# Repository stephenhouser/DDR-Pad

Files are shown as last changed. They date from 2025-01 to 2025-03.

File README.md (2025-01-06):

---
category: woodworking
---

## Todo

- √ Clear acrylic ~ 12x12x 0.354 @ 10 = 180 + $50 shipping
 - https://www.tapplastics.com/product/plastics/cut_to_size_plastic/polycarbonate_sheets/516
 - 2024/01/01 - orderd 10 11x11x0.354" (3/8")
 - $229.94
- √ M6 Screws, M6 Nylon nuts -- Granger
 - 2024/01/03 Picked up nuts, screws on backorder to 2024/01/08
 - $60
	
- Decals ~ $70
 - https://www.bannerbuzz.com/clear-window-decals/p

- Arduino/teensy -- will it be fast enough?
 - perhaps microcontrollers at each pad sending data and lights?

- Metal corners?
 - 16 gague, need sheet brake (Rex?)

- 1.25" SteelTex no-thread pipe -- will it be sturdy enough
 - 1.25 is only in silver color
 - 2 bases, 2 90-deg, 3 poles

## The Build we are working from

- The hardware: [DIY Arcade DDR Metal Dance Pad With LED Under $500](https://www.instructables.com/DIY-Arcade-DDR-Metal-Dance-Pad-With-LED-Under-500/)
- The electronics: [6 Panel DDR USB Controller With LED](https://www.instructables.com/6-Panel-DDR-USB-Controller-With-LED/)

## Other Builds

- [Mystic Steps build](https://www.mysticsteps.com/diy-pad/), uses a AtMega32U (32u chipset for USB I imagine)
- [andrewhlu's build](https://andrewhlu.com/ddr/), uses [STM32L476G board](https://www.digikey.com/en/products/detail/stmicroelectronics/STM32L476G-DISCO/5344355)
- [Sensor Channels](https://www.thingiverse.com/thing:4547247) on Thingiverse, replacements for original DDR

## Making Pads

- https://www.hackmycab.com/?portfolio=arrow-panels-part-1-making-new-polycarb-panels
- https://www.hackmycab.com/?portfolio=arrow-panels-part-2-arrow-decals

## Lights

- [8x6 Lights](https://ddrpad.com/collections/arcade-parts/products/arcade-pad-led-light-mod) for original DDR
- [8x8 addressable LED modules](https://www.amazon.com/WS2812B-Flexible-Individually-Addressable-64Pixels/dp/B09KBZT6LD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) from Amazon
 - ws2812 should be able to do about 64fps with 512 in a chain.
 - will need power injection at each row?
 - https://electronics.stackexchange.com/questions/338248/ws2812b-response-time

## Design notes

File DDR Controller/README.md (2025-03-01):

# DDR Master Controller

Simple keyboard controller for DDR Pad using Teensy 3.2 and teensy's keyboard module (https://www.pjrc.com/teensy/td_keyboard.html)

## TODO

- Use exposed GPIO with jumper or switch to configure for 4-pad (NESW), 8-pad (N, NE, E, SE, S, SW, W, NW), or all 9 pads active.

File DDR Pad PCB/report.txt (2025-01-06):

Info: Front (top side) placement file: '/Users/houser/Projects/DDR Pad (Shawn)/DDR Well v1.0/gerber-v1.0/DDR Pad-top-pos.csv'.
Info: Component count: 16.
Info: Back (bottom side) placement file: '/Users/houser/Projects/DDR Pad (Shawn)/DDR Well v1.0/gerber-v1.0/DDR Pad-bottom-pos.csv'.
Info: Component count: 0.
Info: Full component count: 16.
Info: File generation successful.

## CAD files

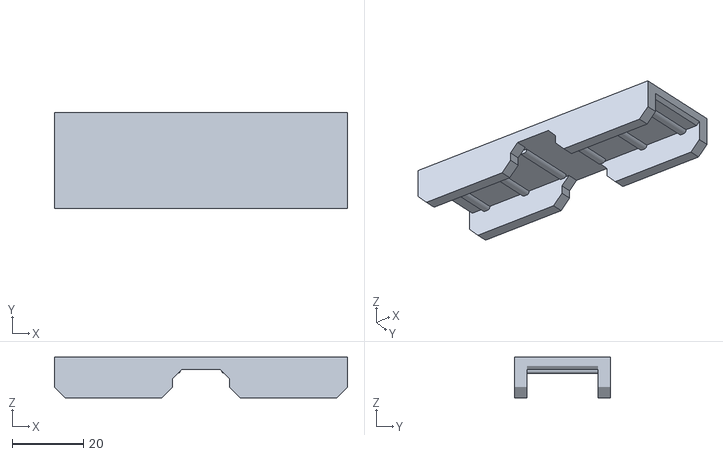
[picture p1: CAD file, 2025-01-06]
Sensor Holders/Sensor+holder+Top.stl
82.0 x 27.0 x 11.4

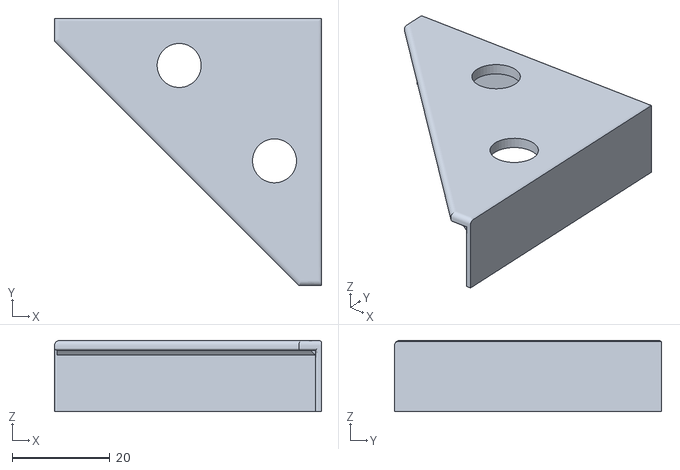
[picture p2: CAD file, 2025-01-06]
Sensor Holders/Active+Corner+Bracket.stl
54.6 x 54.6 x 14.5

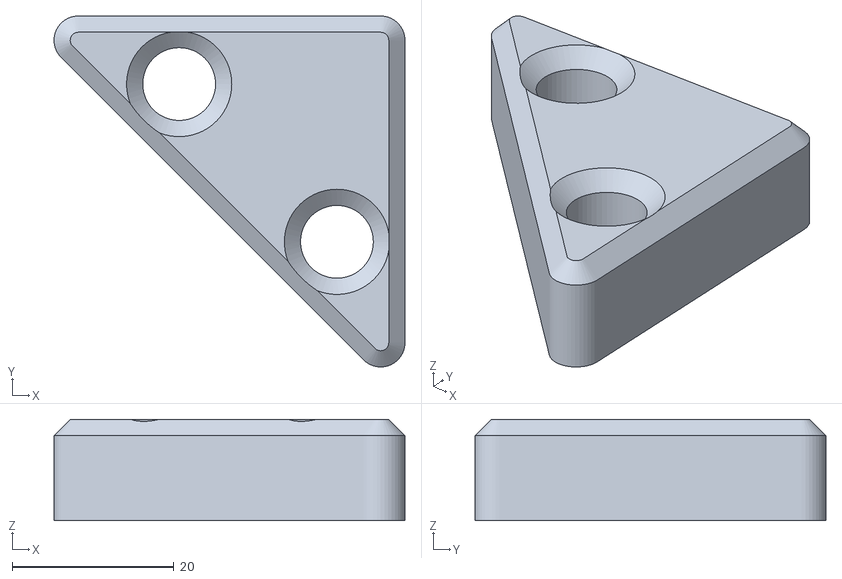
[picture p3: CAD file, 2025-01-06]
Sensor Holders/DDRCornerBracketTrianglev2.stl
43.4 x 43.4 x 12.5

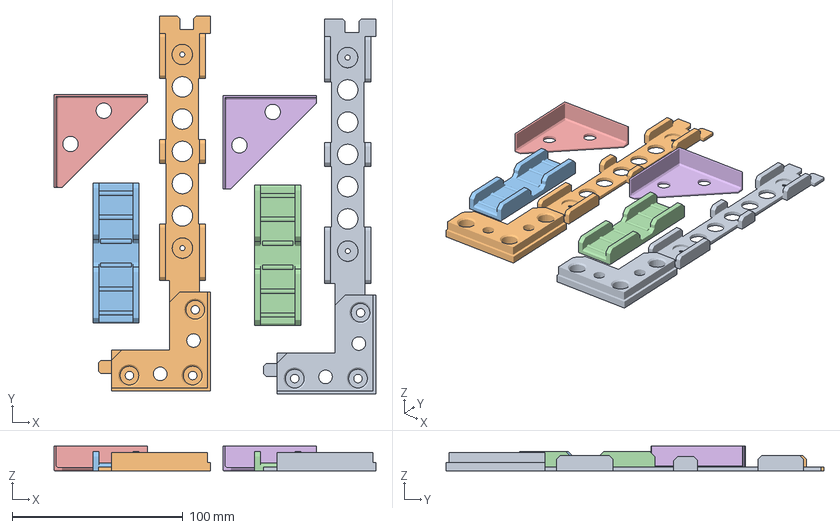
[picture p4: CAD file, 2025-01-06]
Sensor Holders/DDRPActive_Bracket_BaseV2.3mf
188.3 x 221.2 x 14.5 mm
DDRPActive_Bracket_BaseV2.stl x 2
Sensor+holder+Top.stl x 2
Active+Corner+Bracket.stl x 2

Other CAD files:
Sensor Holders/DDRPActive_Bracket_BaseV2.stl

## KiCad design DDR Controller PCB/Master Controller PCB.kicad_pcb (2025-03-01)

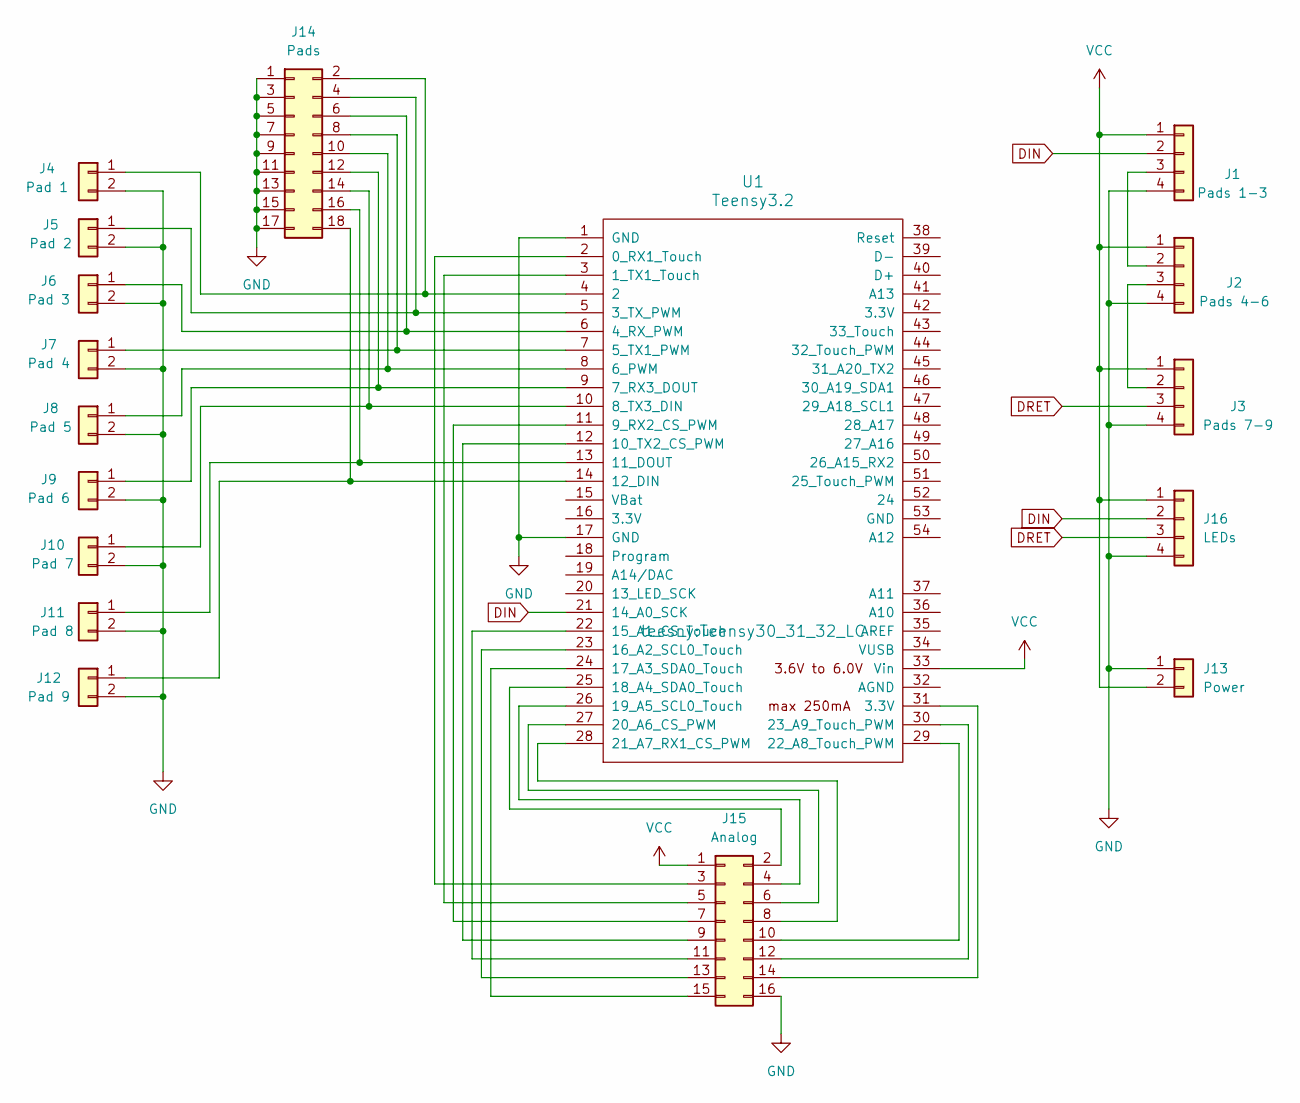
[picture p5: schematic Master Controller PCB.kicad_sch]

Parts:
J1: Pads 1-3; JST_XH_B4B-XH-A_1x04_P2.50mm_Vertical
J2: Pads 4-6; JST_XH_B4B-XH-A_1x04_P2.50mm_Vertical
J3: Pads 7-9; JST_XH_B4B-XH-A_1x04_P2.50mm_Vertical
J4: Pad 1; JST_XH_B2B-XH-A_1x02_P2.50mm_Vertical
J5: Pad 2; JST_XH_B2B-XH-A_1x02_P2.50mm_Vertical
J6: Pad 3; JST_XH_B2B-XH-A_1x02_P2.50mm_Vertical
J7: Pad 4; JST_XH_B2B-XH-A_1x02_P2.50mm_Vertical
J8: Pad 5; JST_XH_B2B-XH-A_1x02_P2.50mm_Vertical
J9: Pad 6; JST_XH_B2B-XH-A_1x02_P2.50mm_Vertical
J10: Pad 7; JST_XH_B2B-XH-A_1x02_P2.50mm_Vertical
J11: Pad 8; JST_XH_B2B-XH-A_1x02_P2.50mm_Vertical
J12: Pad 9; JST_XH_B2B-XH-A_1x02_P2.50mm_Vertical
J13: Power; screw_terminal_01x02_p7.62mm
J14: Pads; PinHeader_2x09_P2.54mm_Vertical
J15: Analog; PinHeader_2x08_P2.54mm_Vertical
J16: LEDs; PinHeader_1x04_P2.54mm_Vertical
U1: Teensy3.2; Teensy30_31_32_LC

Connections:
DIN: J1.2, J16.2, U1.21 (14_A0_SCK)
DRET: J3.3, J16.3
GND: J1.4, J2.4, J3.4, J4.2, J5.2, J6.2, J7.2, J8.2, J9.2, J10.2, J11.2, J12.2, J13.1, J14.1, J14.3, J14.5, J14.7, J14.9, J14.11, J14.13, J14.15, J14.17, J15.16, J16.4, U1.1 (GND), U1.17 (GND)
unnamed: J1.3, J2.2
unnamed: J2.3, J3.2
unnamed: J10.1, J14.14, U1.10 (8_TX3_DIN)
unnamed: J11.1, J14.16, U1.13 (11_DOUT)
unnamed: J12.1, J14.18, U1.14 (12_DIN)
unnamed: J4.1, J14.2, U1.4 (2)
unnamed: J5.1, J14.4, U1.5 (3_TX_PWM)
unnamed: J6.1, J14.6, U1.6 (4_RX_PWM)
unnamed: J7.1, J14.8, U1.7 (5_TX1_PWM)
unnamed: J8.1, J14.10, U1.8 (6_PWM)
unnamed: J9.1, J14.12, U1.9 (7_RX3_DOUT)
unnamed: J15.2, U1.25 (18_A4_SDA0_Touch)
unnamed: J15.3, U1.2 (0_RX1_Touch)
unnamed: J15.4, U1.26 (19_A5_SCL0_Touch)
unnamed: J15.5, U1.3 (1_TX1_Touch)
unnamed: J15.6, U1.27 (20_A6_CS_PWM)
unnamed: J15.7, U1.11 (9_RX2_CS_PWM)
unnamed: J15.8, U1.28 (21_A7_RX1_CS_PWM)
unnamed: J15.9, U1.12 (10_TX2_CS_PWM)
unnamed: J15.10, U1.29 (22_A8_Touch_PWM)
unnamed: J15.11, U1.22 (15_A1_CS_Touch)
unnamed: J15.12, U1.30 (23_A9_Touch_PWM)
unnamed: J15.13, U1.23 (16_A2_SCL0_Touch)
unnamed: J15.14, U1.31 (3.3V)
unnamed: J15.15, U1.24 (17_A3_SDA0_Touch)
VCC: J1.1, J2.1, J3.1, J13.2, J15.1, J16.1, U1.33 (Vin)

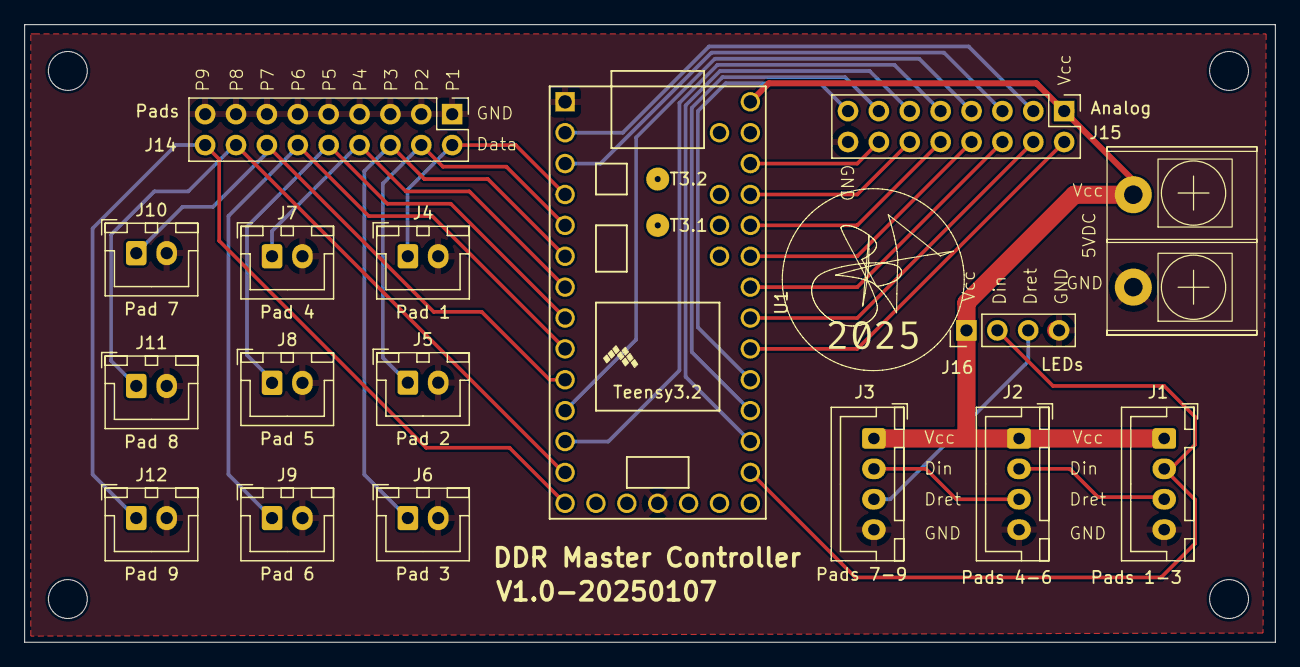
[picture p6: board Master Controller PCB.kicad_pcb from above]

Board: 2 copper layers, 102.9 x 50.8 mm, 17 parts (0 on the bottom side), 29 nets.

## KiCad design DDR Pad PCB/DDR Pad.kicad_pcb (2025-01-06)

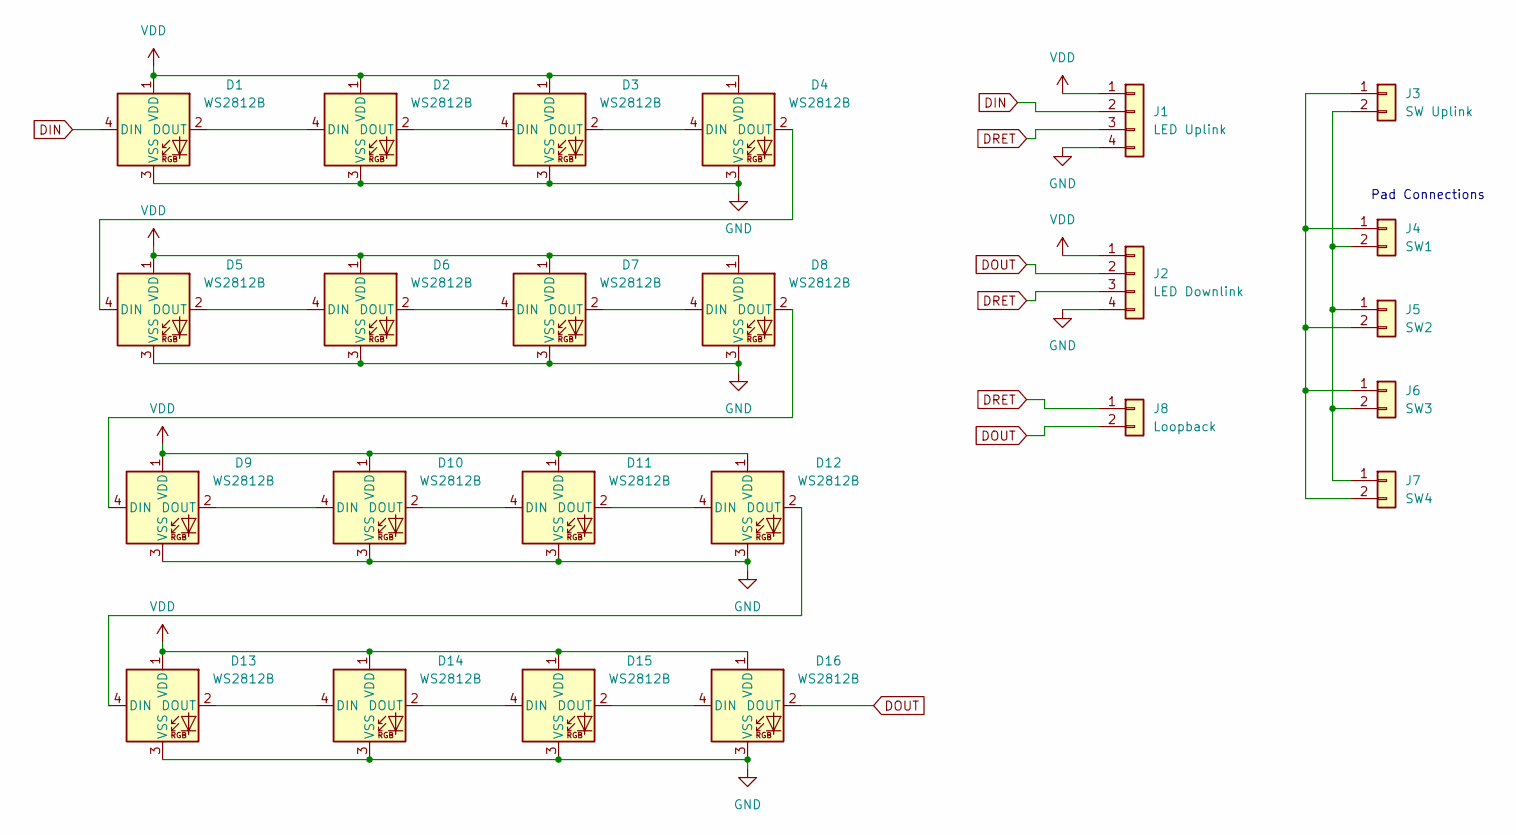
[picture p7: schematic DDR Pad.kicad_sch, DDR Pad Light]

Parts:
D1, D2, D3, D4, D5, D6, D7, D8, D9, D10, D11, D12, D13, D14, D15, D16: WS2812B; LED_WS2812B_PLCC4_5.0x5.0mm_P3.2mm; LCSC C2846931
J1: LED Uplink; JST_XH_S4B-XH-A_1x04_P2.50mm_Horizontal
J2: LED Downlink; JST_XH_S4B-XH-A_1x04_P2.50mm_Horizontal
J3: SW Uplink; JST_XH_S2B-XH-A-1_1x02_P2.50mm_Horizontal
J4: SW1; JST_XH_S2B-XH-A-1_1x02_P2.50mm_Horizontal
J5: SW2; JST_XH_S2B-XH-A-1_1x02_P2.50mm_Horizontal
J6: SW3; JST_XH_S2B-XH-A-1_1x02_P2.50mm_Horizontal
J7: SW4; JST_XH_S2B-XH-A-1_1x02_P2.50mm_Horizontal
J8: Loopback; PinHeader_1x02_P2.54mm_Vertical

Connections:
DIN: D1.4 (DIN), J1.2
DOUT: D16.2 (DOUT), J2.2, J8.2
DRET: J1.3, J2.3, J8.1
GND: D1.3 (VSS), D2.3 (VSS), D3.3 (VSS), D4.3 (VSS), D5.3 (VSS), D6.3 (VSS), D7.3 (VSS), D8.3 (VSS), D9.3 (VSS), D10.3 (VSS), D11.3 (VSS), D12.3 (VSS), D13.3 (VSS), D14.3 (VSS), D15.3 (VSS), D16.3 (VSS), J1.4, J2.4
unnamed: D1.2 (DOUT), D2.4 (DIN)
unnamed: D2.2 (DOUT), D3.4 (DIN)
unnamed: D3.2 (DOUT), D4.4 (DIN)
unnamed: D4.2 (DOUT), D5.4 (DIN)
unnamed: D5.2 (DOUT), D6.4 (DIN)
unnamed: D6.2 (DOUT), D7.4 (DIN)
unnamed: D7.2 (DOUT), D8.4 (DIN)
unnamed: D8.2 (DOUT), D9.4 (DIN)
unnamed: D9.2 (DOUT), D10.4 (DIN)
unnamed: D10.2 (DOUT), D11.4 (DIN)
unnamed: D11.2 (DOUT), D12.4 (DIN)
unnamed: D12.2 (DOUT), D13.4 (DIN)
unnamed: D13.2 (DOUT), D14.4 (DIN)
unnamed: D14.2 (DOUT), D15.4 (DIN)
unnamed: D15.2 (DOUT), D16.4 (DIN)
unnamed: J3.1, J4.1, J5.2, J6.1, J7.2
unnamed: J3.2, J4.2, J5.1, J6.2, J7.1
VDD: D1.1 (VDD), D2.1 (VDD), D3.1 (VDD), D4.1 (VDD), D5.1 (VDD), D6.1 (VDD), D7.1 (VDD), D8.1 (VDD), D9.1 (VDD), D10.1 (VDD), D11.1 (VDD), D12.1 (VDD), D13.1 (VDD), D14.1 (VDD), D15.1 (VDD), D16.1 (VDD), J1.1, J2.1

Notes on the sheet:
Pad Connections

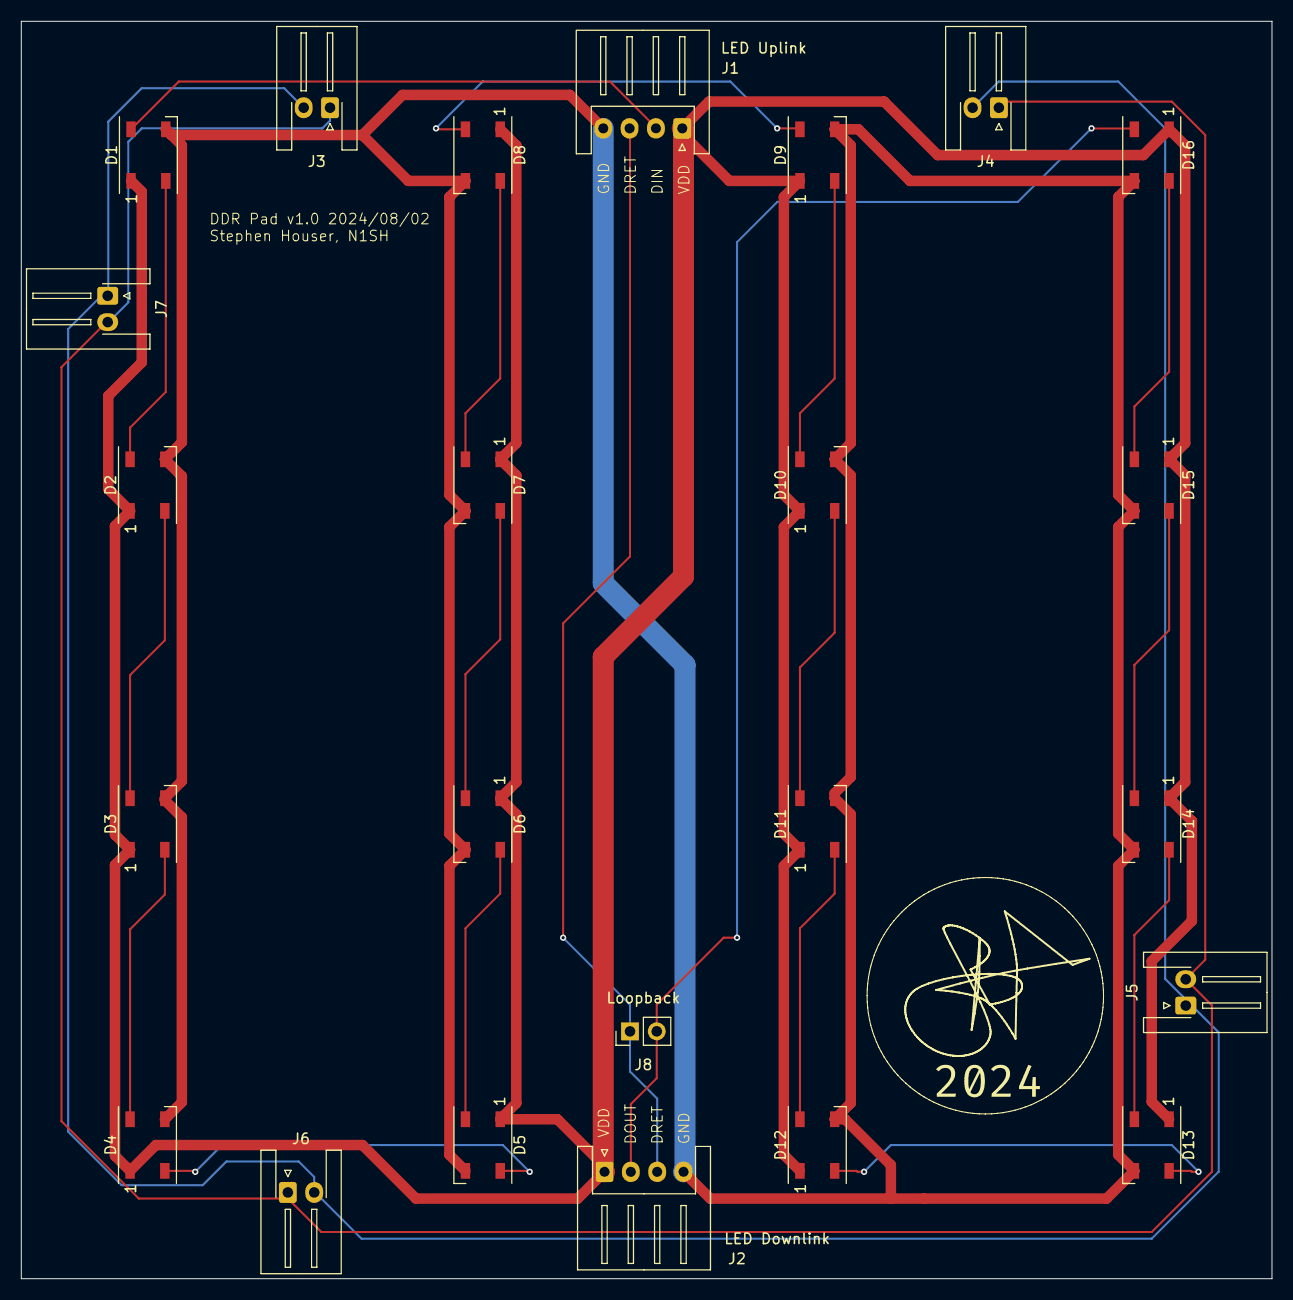
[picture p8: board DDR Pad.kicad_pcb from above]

Board: 2 copper layers, 118.7 x 119.4 mm, 24 parts (0 on the bottom side), 22 nets.

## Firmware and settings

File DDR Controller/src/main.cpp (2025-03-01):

#include <Arduino.h>
#include <Keyboard.h>
#include <Bounce2.h>
#include <FastLED.h>

// number of pads/squares
#define NUM_PADS 		9
// number of LEDs on each pad
#define LEDS_PER_PANEL 	16
#define NUM_LEDS		(NUM_PADS * LEDS_PER_PANEL)

// Overall brightness
#define BRIGHTNESS 		192
// Pin to use to control LEDs
#define LED_DATA_PIN 	14

// Pins to use for button inputs
#define PAD_1 			2
#define PAD_2 			3
#define PAD_3 			4
#define PAD_4 			5
#define PAD_5 			6
#define PAD_6 			7
#define PAD_7 			8
#define PAD_8 			11
#define PAD_9 			12

// Pin to use for 4 or 9 pad toggle switch
#define PAD_TOGGLE_SW	17

/* Enable or disable pads; 0 disabled, 1 enabled */
int pad_enabled[NUM_PADS] = {1, 1, 1, 1, 1, 1, 1, 1, 1};
/* Pins for button inputs for each pad */
int button_pin[NUM_PADS] = {PAD_1, PAD_2, PAD_3, PAD_4, PAD_5, PAD_6, PAD_7, PAD_8, PAD_9};
Bounce2::Button button[NUM_PADS];
Bounce2::Button pad_toggle;

#if defined(USB_KEYBOARDONLY)
int button_keys[NUM_PADS] = {KEY_1, KEY_2, KEY_3, KEY_4, KEY_5, KEY_6, KEY_7, KEY_8, KEY_9};
#endif

/* array of LED colors for FastLED */
CRGB leds[NUM_LEDS];

/* Change state of LEDs for specific pad, value=0 for off, 1 for on (white) */
void light_pad(int pad, int value) {
	/* compute which LEDs to turn on. */
	int led_start = pad * LEDS_PER_PANEL;
	int led_end = led_start + LEDS_PER_PANEL;

	for (int i = led_start; i < led_end; i++) {
		leds[i] = value ? CRGB::White : CRGB::Black;
	}

	FastLED.show();
}

void light_active_pads() {
	for (int pad = 0; pad < NUM_PADS; pad++) {		
		Serial.print(pad);

		if (pad_enabled[pad]) {
			Serial.print("=enabled ");
			light_pad(pad, 1);

			delay(250);
			light_pad(pad, 0);
		} else {
			Serial.print("=disabled ");
		}

		delay(1);
	}

	Serial.println();
}

void setup_4pad() {
	int pad4[NUM_PADS] = {0, 1, 0, 1, 0, 1, 0, 1, 0};
	for (int p = 0; p < NUM_PADS; p++) {
		pad_enabled[p] = pad4[p];
	}

	light_active_pads();
}

void setup_8pad() {
	int pad8[NUM_PADS] = {1, 1, 1, 1, 0, 1, 1, 1, 1};
	for (int p = 0; p < NUM_PADS; p++) {
		pad_enabled[p] = pad8[p];
	}

	light_active_pads();
}

void setup_9pad() {
	int pad9[NUM_PADS] = {1, 1, 1, 1, 1, 1, 1, 1, 1};
	for (int p = 0; p < NUM_PADS; p++) {
		pad_enabled[p] = pad9[p];
	}
	
	light_active_pads();
}


/* Set up LED pads, really just lights up each one for testing. */
void setup_pads() {
	Serial.print("Initialize pads...");

	FastLED.addLeds<NEOPIXEL, LED_DATA_PIN>(leds, NUM_LEDS);
	FastLED.setBrightness(BRIGHTNESS);

	setup_9pad();
	Serial.println(" done.");
}

/* Light up pads based on button states; on=lit, off=unlit. */
void light_pads_loop() {
	for (int b = 0; b < NUM_PADS; b++) {
		if (pad_enabled[b] && button[b].changed()) {
			light_pad(b, button[b].isPressed());
		}
	}

	FastLED.show();
}

void setup_buttons() {
	Serial.print("Initialize buttons...");
    for (int pad = 0; pad < NUM_PADS; pad++) {
        if (pad_enabled[pad]) {
			button[pad].attach(button_pin[pad], INPUT_PULLUP);
			button[pad].interval(5);
			button[pad].setPressedState(LOW);
		}
	}

	Serial.println(" done.");
}

/* Reads all button inputs, sets button[] based on read values. */
void read_buttons_loop() {
    for (int pad = 0; pad < NUM_PADS; pad++) {
        if (pad_enabled[pad]) {
			button[pad].update();
        }
    }
}

void send_keys_loop() {
#if defined(USB_KEYBOARDONLY)
	for (int pad = 0; pad < NUM_PADS; pad++) {
		if (pad_enabled[pad]) {
			if (button[pad].fell()) {
				Keyboard.press(button_keys[pad]);
			} else if (button[pad].rose()) {
				Keyboard.release(button_keys[pad]);
			}
		}
	}
#else
	for (int pad = 0; pad < NUM_PADS; pad++) {
		if (pad_enabled[pad]) {
			if (button[pad].fell()) {
				Serial.printf("%d down\n", pad);
			} else if (button[pad].rose()) {
				Serial.printf("%d up\n", pad);
			}
		}
	}
#endif
}

void setup_pad_toggle() {
	pad_toggle.attach(PAD_TOGGLE_SW, INPUT_PULLUP);
	pad_toggle.interval(5);
	pad_toggle.setPressedState(LOW);
}

void pad_toggle_loop() {
	pad_toggle.update();
	if (pad_toggle.changed()) {
		if (pad_toggle.isPressed()) {
			setup_4pad();
		} else {
			setup_9pad();
		}
	}
}

/* Arduino setup, initialize serial, FastLED, and button pins.
 * Play short sequence to light up all pads briefly.
 */
void setup() {
	Serial.begin(9600);
	Serial.println("Starting...");

	setup_pads();
	setup_buttons();
	setup_pad_toggle();

	Serial.println("Ready!");
}

/* Arduino loop, read buttons and light up pads. */
int counter = 0;
int butt = 0;

void loop() {
	read_buttons_loop();
	send_keys_loop();
	light_pads_loop();

	pad_toggle_loop();

	delay(1);
	// if (counter++ == 100) {
	// 	Serial.printf("light %d\n", butt);
	// 	counter = 0;
	// 	light_pad(butt, 1);
	// 	FastLED.show();

	// 	// delay(111);
	// 	delay(250);
	// 	light_pad(butt, 0);
	// 	FastLED.show();

	// 	butt = (butt + 1) % NUM_PADS;
	// }
}

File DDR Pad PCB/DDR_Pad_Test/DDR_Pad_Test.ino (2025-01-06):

// /Users/houser/Library/Arduino15/packages/arduino/tools/avrdude/6.3.0-arduino17/bin/avrdude -v -V -patmega328p -carduino "-P/dev/cu.usbserial-840" -b115200

#include <FastLED.h>
 
// How many leds in your strip?
#define NUM_LEDS        144
#define LED_DATA_PIN    A0
#define BRIGHTNESS      32

#define NUM_PADS         9
#define LEDS_PER_PANEL  16

#define PAD_1           2 //
#define PAD_2           3 //
#define PAD_3           4 //
#define PAD_4           5 //
#define PAD_5           6 //
#define PAD_6           7
#define PAD_7           8
#define PAD_8           9
#define PAD_9           10  // 
                    
int pad_enabled[NUM_PADS]  = {1, 1, 1, 1, 1, 1, 1, 1, 1};
                                                          // input pin for buttons
int button_pin[NUM_PADS]  = {PAD_1, PAD_2, PAD_3, PAD_4, PAD_5, PAD_6, PAD_7, PAD_8, PAD_9};
int button[NUM_PADS]      = {0, 0, 0, 0, 0, 0, 0, 0, 0};  // current button state
int button_last[NUM_PADS] = {0, 0, 0, 0, 0, 0, 0, 0, 0};  // previous button state
CRGB leds[NUM_LEDS];                                      // Array of LEDs for FastLED
 
void read_buttons() {
  // for (int b = 0; b < 1; b++) {
  for (int b = 0; b < NUM_PADS; b++) {
    if (pad_enabled[b]) {
      button_last[b] = button[b];
      button[b] = digitalRead(button_pin[b]);
    }
  }
}

void light_pad(int pad, int value) {
  int led_start = pad * LEDS_PER_PANEL;
  int led_end   = (pad + 1) * LEDS_PER_PANEL;

  CRGB color = CRGB::White;
  if (value == HIGH) {
    color = CRGB::Black;
  }

  for(int i = led_start; i < led_end; i++) {
    leds[i] = color;
  }
}

void light_pads() {
  for (int b = 0; b < NUM_PADS; b++) {
    if (pad_enabled[b] && (button[b] != button_last[b])) {
      char buffer[50];
      sprintf(buffer, "%d:%d", b, button[b]);
      Serial.println(buffer);

      light_pad(b, button[b]);
    }
  }

  FastLED.show();
}

void setup() { 
  Serial.begin(115200);
  Serial.println("Starting...");

  FastLED.addLeds<NEOPIXEL, LED_DATA_PIN>(leds, NUM_LEDS);
  FastLED.setBrightness(BRIGHTNESS);

  for (int b = 0; b < NUM_PADS; b++) {
    if (pad_enabled[b]) {
      Serial.print("Enable pad ");
      Serial.println(b+1);

      light_pad(b, LOW);
      FastLED.show();

      pinMode(button_pin[b], INPUT_PULLUP);
      button[b] = digitalRead(button_pin[b]);
      button_last[b] = button[b];

      delay(111);
      light_pad(b, HIGH);
      FastLED.show();
    }
  }

  Serial.println("Ready!");
}

void loop() { 
  read_buttons();
  light_pads();
}





/*

void fadeall() { 
  for(int i = 0; i < NUM_LEDS; i++) { 
    leds[i].nscale8(250);
  } 
}


    if (lastButtonState == HIGH) {
      for(int i = 0; i < NUM_LEDS; i++) {
        leds[i] = CRGB::Black;
      }
      FastLED.show(); 
      delay(25);
    } else {
      // First slide the led in one direction
      for(int i = 0; i < NUM_LEDS; i++) {
          // Set the i'th led to red 
          leds[i] = CHSV(hue++, 255, 255);
          // Show the leds
          FastLED.show(); 
          // now that we've shown the leds, reset the i'th led to black
          // leds[i] = CRGB::Black;
          fadeall();
          // Wait a little bit before we loop around and do it again
          delay(25);
      }
  
      // Now go in the other direction.  
      for(int i = (NUM_LEDS)-1; i >= 0; i--) {
          // Set the i'th led to red 
          leds[i] = CHSV(hue++, 255, 255);
          // Show the leds
          FastLED.show();
          // now that we've shown the leds, reset the i'th led to black
          // leds[i] = CRGB::Black;
          fadeall();
          // Wait a little bit before we loop around and do it again
          delay(25);
      }
    }
    */

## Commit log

2025-01-07 teensy based controller that acts as a keyboard
2025-03-01 rename, reorganize
    [Master Controller PCB.kicad_pcb, Master Controller PCB.kicad_sch, bom.csv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]
2025-03-13 change to teensy 4.0
